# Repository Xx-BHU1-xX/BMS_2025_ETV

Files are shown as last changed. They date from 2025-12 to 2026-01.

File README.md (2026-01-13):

## Project archive for the 2025 ETV BMS
- Refer to the `hardware` section for design choices and PCB files.
- Refer to the `software` section for firmware dev.

## Yet to be implemented:
- Charging control and charger CAN comms
	- Control charging current and voltage according to INR1650 charge specs
	- J1939 CAN implementation for commanding charging current and voltage 
	- Should be relatively straightforard to implement with new task
- Inital SOH estimation
	- Detailed in the task description for `TaskUpdateSOC` 
- DCIR history
	- Store DCIR values in EEPROM for recovery in the next power cycle

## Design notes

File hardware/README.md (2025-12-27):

# Battery Management System (BMS)

---

## Architecture evolution

### Earlier version
- Used **LTC6804-based slave boards (DC1894B)** with a **Linduino (DC2026)** as the isoSPI master.
- The entire system ran on the **ATmega328P** on the DC2026.
- SRAM was very limited (~2 KB), which was barely enough for:
  - 72× cell voltages, SOC, DCIR values
  - filtering / fault flags
- This became the main bottleneck as features were added.

---

### Revised architecture
- High-level processing was offloaded to an **ESP32**.
- The **DC2026** was retained only for reliable LTC6804 isoSPI communication.
- Direct isoSPI from the ESP32 was avoided to keep hardware and isolation simpler (and to avoid porting the LTC sketchbook :)

---

## Communication and isolation
- **ESP32** is referenced to **GLV**.
- **Linduino (DC2026)** is referenced to **TS**.
- Communication between the two is via an **isolated UART**.

---

## Additional features
- CAN communication for vehicle integration.
- Redundant isolated current sensing:
  - Hall-effect sensor (HBO300 fully differential)
  - Shunt-based sensor (VAT4300 wireless)

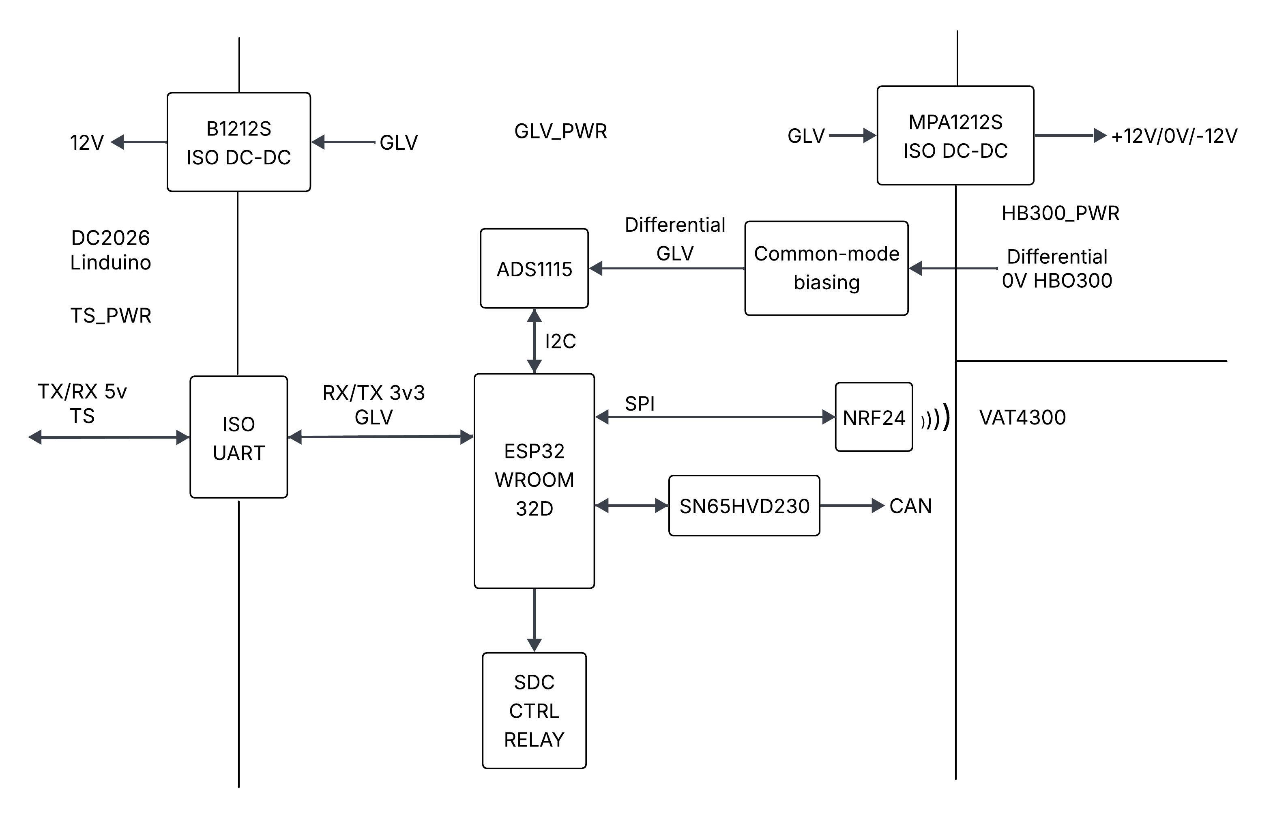
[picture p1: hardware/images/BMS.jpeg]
BMS architecture


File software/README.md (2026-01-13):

## Firmware overview

The BMS firmware runs on the ESP32 using FreeRTOS and is structured as a set of independent tasks, each responsible for one clear function (cell monitoring, SOC/DCIR estimation, current sensing, balancing, fault handling, comms, etc). Most tasks are implemented as simple state machines and communicate with each other using RTOS primitives. The overall focus is on robustness, predictable behavior, and making sure safety-critical logic (especially SDC control) cannot fail.

---

## General firmware practices

### RTOS usage
- Standard FreeRTOS practices are followed:
  - one task per logical function
  - clear ownership of peripherals
  - explicit synchronization between tasks

---

### Data sharing between tasks
- Data between tasks is shared using **queues**.
- In most cases, only the **latest value** matters and older values are irrelevant.
- Hence, almost all queues are created with **length = 1**.
- Writes use `xQueueOverwrite()` to always push the latest value.
- Reads use `xQueuePeek()` so values can be read **non-destructively**.
- This avoids issues like conflicting writes and read/write races.
- Stale data detection is additonaly implemented in fault detection and handling.

---

### Resource management
- Shared peripherals (I2C, SPI, CAN, UART, etc.) are protected using **mutexes**.
- If a task needs a peripheral, it:
  1. takes the mutex  
  2. uses the peripheral  
  3. releases the mutex
- Once a task has taken a mutex, no other task can access that peripheral, even if the original task gets preempted.
- This ensures the reason the task needed the peripheral in the first place doesn’t get corrupted by another task.

---

### Interrupt handling
- ISRs themselves are not part of the RTOS.
- Interrupts are handled using **short ISRs** that simply notify a waiting task.
- The actual processing is always done in task context.

**Important**
- The task must already be waiting for the interrupt **before** the interrupt fires.
- In practice, this means:
  - perform the action
  - wait for the interrupt **in the same state**
- The wait is intentionally not moved into the next state, because any delay between states could cause the interrupt to arrive when the task isn’t waiting, adding unnecessary latency or missing the event altogether.

For task descriptions, refer 
[Full task descriptions (PDF)](docs/BMS_25.pdf)

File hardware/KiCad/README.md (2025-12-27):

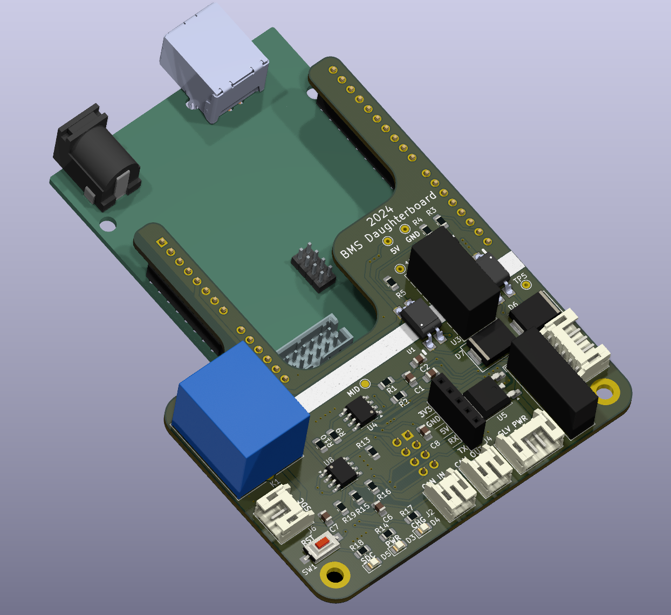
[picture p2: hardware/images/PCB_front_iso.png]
PCB front iso

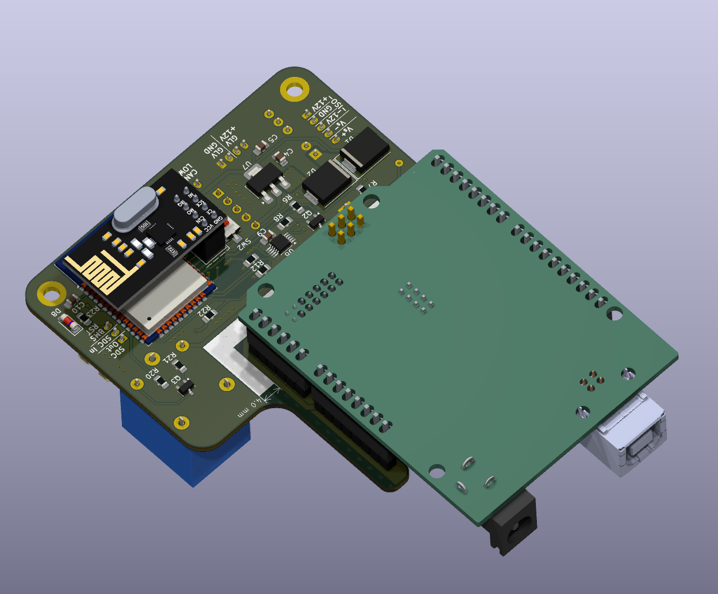
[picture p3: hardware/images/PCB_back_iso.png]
PCB back iso


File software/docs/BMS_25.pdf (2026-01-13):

# Task descriptions

## void TaskLinduinoCVComms(void *pvParameters)

This task handles communication with the Linduino (DC2026) over an isolated UART.

### Communication scheme

### ESP32 → Linduino (request)

- The ESP32 requests 12× cell voltages for a given segment and sends the balancing configuration for that segment.
- The balance configuration is stored as a uint16_t, where each bit represents whether balancing is ON/OFF for a module:
BAL[segment_index] = 0x0XXX (LSB corresponds to module 0).
- Each request packet is 1 byte, encoded as:
- Segment ID (3 bits)
Identifies the requested segment (1–6).
- Balance Index (2 bits)
Selects which 3-bit slice of the 12-bit balance word: ■ 0 → BAL[2:0]
■ 1 → BAL[5:3]
■ 2 → BAL[8:6]
■ 3 → BAL[11:9]
- Balance Config (3 bits)
Balancing ON/OFF for the selected 3 modules.

Notes

- Four request bytes are sent (one per balance index).
- Bytes are sent 1 ms apart.
- Packet is self-identifying; order does not matter.

### Linduino → ESP32 (response)

- The Linduino receives the 4 bytes and reconstructs the full 12-bit balance configuration for the requested segment.
- It responds with 26 bytes in the following format:
- Byte 0 : Segment ID (Same as request, extended to 8 bits (0x01 - 0x06))
- Byte 1–24 : 12 × uint16_t Cell Voltages (big-endian)
- Byte 25 : CRC (8-bit)

Details

- Cell voltages start from module 0.
- Each cell voltage is uint16_t (actual CellV * 10000)
- CRC is calculated over the 12 × 16-bit cell voltage data only.
- CRC polynomial: 100000111

### ESP32 receive handling

- The ESP32 reads the 26-byte response.
- It first checks that the segment index matches the requested segment.
- If not, the serial stream is flushed and the packet is ignored.
- The CRC is verified.
- If valid, the received cell voltages are pushed to the cell-voltage queue.
- The ESP32 then requests data for the next segment, and the cycle repeats.

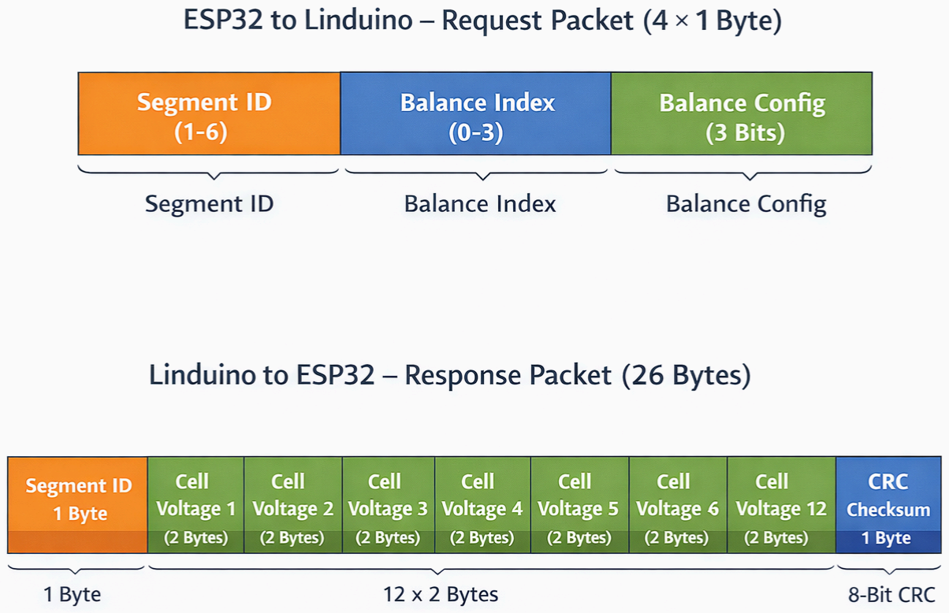
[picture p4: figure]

## void TaskUpdateSOC(void *pvParameters)

This task updates SOC using two methods and then fuses them.

### Method 1: SOC1 (voltage-based)

- The task estimates OCV using:
- OCV = CellV + (TS_current + I_balance_if_ON) * DCIR
- It then estimates SOC from OCV using your piecewise 3rd-order fit:
- SOC1 = OCV2SOC(OCV)

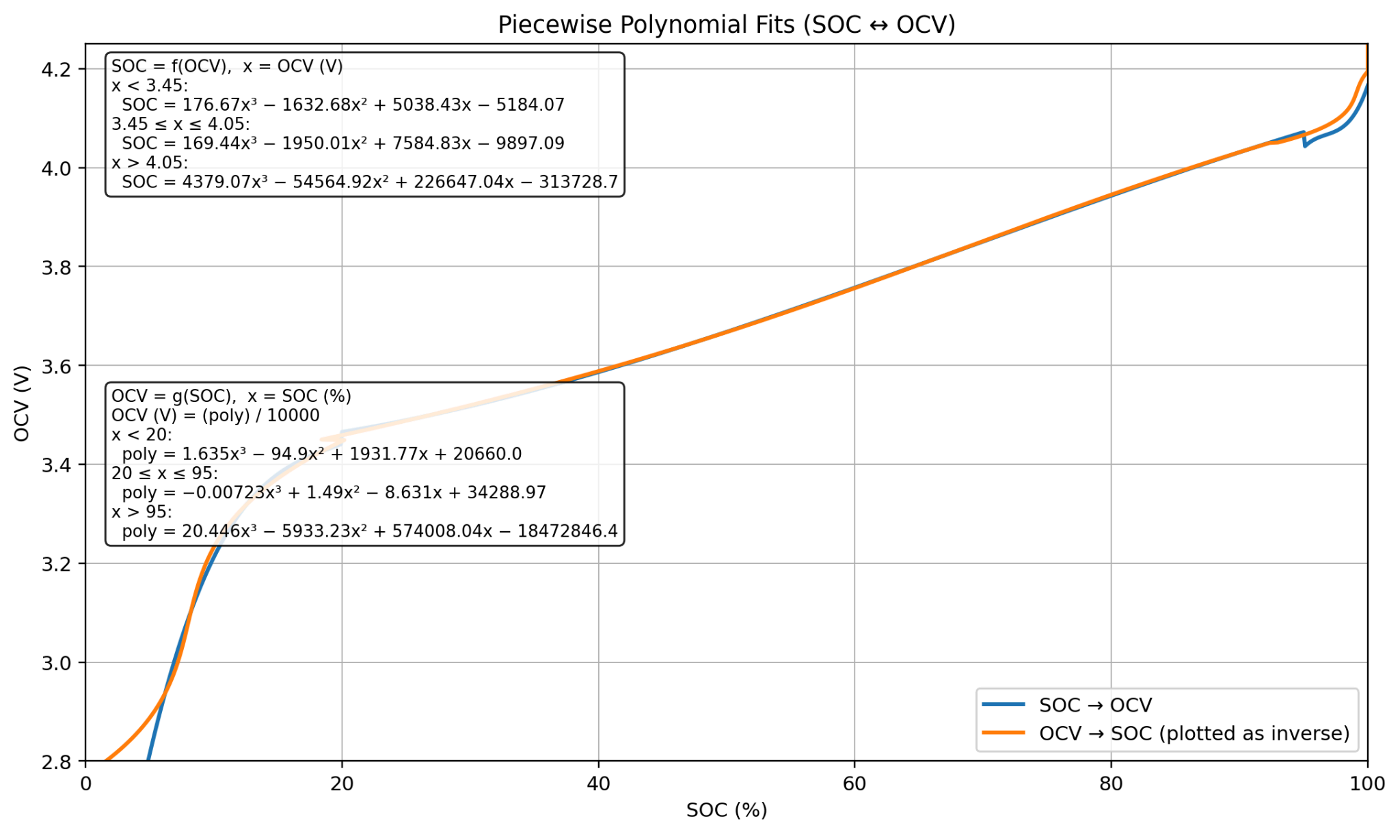
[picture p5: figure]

### Method 2: SOC2 (coulomb counting)

- SOC2 is updated using coulomb counting:
- SOC2 = SOC2_prev - (TS_current * Δt) / MOD_Capacity
- Here MOD_Capacity = 25Ah, and Δt = (current_update_time - last_update_time).

### Fusion: complementary filter

- SOC1 is trusted only at low current, so the blend factor is:
- alpha = max(0, (1 - abs(TS_current)/I_threshold))
- Final SOC is:
- SOC_final = alpha*SOC1 + (1-alpha)*SOC2

Notes

- SOC2 needs initialization, so on the first update:
- SOC1 = SOC2 = OCV2SOC(OCV)
- If the actual module capacity is less than MOD_Capacity (25Ah), SOC2 will change slower than SOC1 during discharge.
- The ratio ΔSOC2 / ΔSOC1 can be used as a rough SOH estimate (since SOC2 assumes ideal capacity).
- There are small discontinuities at the boundaries of the piecewise polynomial fit.
- Even with these discontinuities, the fits were chosen such that within each region, repeated inter-conversion OCV → SOC → OCV → … will still converge, even in the presence of floating-point rounding error.
- This task starts only after the first round of cellVs for all 6 segments have been received (TaskLinduinoCVComms gives a notification)

## void TaskUpdateDCIR(void *pvParameters)

This task updates DCIR dynamically during operation.

### DCIR update equation

DCIR is estimated as:

- DCIR_new = (SOC2OCV(SOC_final) - CellV) / (TS_current + I_balance_if_ON)

Limits + jump filtering

The new DCIR is accepted only if:

- DCIR_MIN_LIMIT < DCIR_new < DCIR_MAX_LIMIT
- AND abs(DCIR_new - DCIR_old) < DCIR_JUMP_LIMIT
- Example limits:
- DCIR_MIN_LIMIT = 2500 µΩ
- DCIR_MAX_LIMIT = 5000 µΩ
- DCIR_JUMP_LIMIT = 1000 µΩ

### Smoothing

If the limits pass, DCIR is updated using exponential smoothing:

- DCIR = beta*DCIR_new + (1-beta)*DCIR_old

Note

- The clipping + jump limit + smoothing is mainly to reduce noise and to average out effects like cell polarization (so DCIR doesn’t go nuts due to transients).
- This task only starts after the first round of SOCs have been estimated for all modules (TaskUpdateSOC) gives a notification

## void TaskADS1115(void *pvParameters)

- Interfacing with all peripherals like ADS1115 (I2C), NRF24 (SPI), CAN, etc are handled using state machines.
- Of course the Adafruit library exists for interfacing with the ADS1115, but it suffers from a flaw. It uses polling (the OS bit of the config register is polled continuously to check if the conversion is complete). However this isn’t ideal for RTOS as other tasks could be run during the ADC conversion time. Hence an interrupt triggered, thread safe driver was built from scratch.
- Shared bus/resources are protected using mutexes (see Resource management section in the intro).
- ADS1115 conversions run in single-shot mode.
- The ESP32 starts conversions, and the I2C read is triggered by the active-low RDY interrupt on GPIO14.
- ADS1115 I2C address is 0b1001000 (0x48) since ADDR is tied to GND.

### State 0 — Write config (setup)

- Write 0x0380 to Config register (pointer = 0x01).
- Bitfields:
- OS (bit 15) = 0 (not starting conversion yet)
- MUX (14:12) = 000 (AIN0 − AIN1)
- PGA (11:9) = 001 (±4.096 V, since HBO300 outputs ±4 V)
- MODE (8) = 1 (single-shot)
- DR (7:5) = 100 (128 SPS default, not critical in single-shot)
- COMP_MODE (4) = 0 (don’t care for RDY)
- COMP_POL (3) = 0 (active-low RDY)
- COMP_LAT (2) = 0 (don’t care for RDY)
- COMP_QUE (1:0) = 00 (anything except 11 works)
- If the I2C write succeeds (all bytes ACK’d), go to State 1.

### State 1 — Write Lo_thresh (enable RDY)

- Write 0x0000 to Lo_thresh (pointer = 0x02).
- RDY mode needs MSB of Lo_thresh = 0.
- If the I2C write succeeds, go to State 2.

### State 2 — Write Hi_thresh (enable RDY)

- Write 0x8000 to Hi_thresh (pointer = 0x03).
- RDY mode needs MSB of Hi_thresh = 1.
- If the I2C write succeeds, go to State 3.

### State 3 — Start conversion + wait for RDY + read

- Write 0x8380 to Config (same as State 0, but OS = 1 to start conversion).
- Wait for the interrupt notification from the RDY pin.
- The same state that triggers conversion also waits for the notification.
- This is intentional because the state machine has a 2 ms delay between states, and splitting the wait into another state could add up to ~2 ms of extra latency if the RDY interrupt arrives when the task isn’t scheduled.
- Once the notification is received from the ISR, write 0x00 to the pointer register to select Conversion register (pointer = 0x00).
- Request a 2-byte I2C read and read the conversion register.
- If 2 bytes are received successfully, go to State 4.

### State 4 — Process + queue

- Read the 2 bytes from the I2C buffer into memory.
- Use the first 10 readings to estimate an average zero-current bias.
- Push the raw conversion value into the ADS1115Current queue.
- Every ADS1115_CONFIG_REWRITE_CYCLES (100 conversions), rewrite config from State 0–2.
- Otherwise, go back to State 3 and start the next conversion.

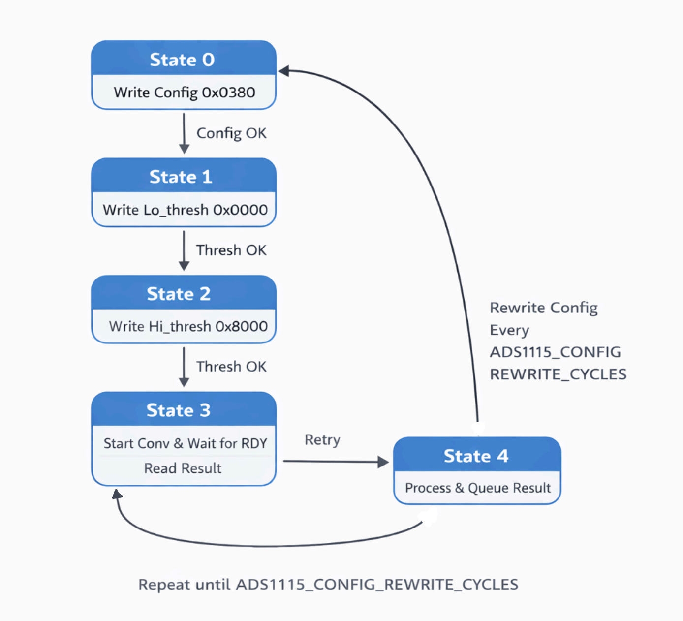
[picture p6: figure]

## void TaskVAT4300(void *pvParameters)

- The VAT4300 shunt uses an nRF24 link with a proprietary protocol.
- The protocol + config was reverse engineered by Robert Flately (https://www.youtube.com/redirect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) (Youtube video) (https://www.youtube.com/watch?v=S0-O9cTS9Uw)
- This task is basically a clean, state-machine based, thread-safe version of that approach.
- Implementation uses the RF24 Arduino library.

### Comms scheme (state machine)

### State 0 — Radio setup (address + frequency)

- The VAT4300 needs two critical settings:
- VAT4300_address
- VAT4300_frequency
- These are normally set by the original base station, but since that was lost, they were recovered by probing the VAT4300 nRF24 SPI lines on a scope + serial decode.
- The TX/RX pipes are opened (pipe 0) using the correct address and frequency.
- Auto-ACK is enabled for pipe 0.

### State 1 — Transmit frame + wait for a valid RX (IRQ handling)

- Default TX payload format is:
- 0xAA 0x04 0x01 <VAT4300_address> <28 bytes of 0x00>
- For the first initialization frame:
- TX_payload[2] = 0xFF
- TX_payload[4] = VAT4300_address + 0xAD
- For all normal frames after init:
- TX_payload[2] = 0x01
- TX_payload[4] = VAT4300_address + 0xAF
- The frame is transmitted, and then the radio switches to listening mode.

Important: NRF24 IRQ behavior

- IRQ (active-low) asserts for multiple reasons:
- TX success (ACK received) (radio.write() returns true)
- TX fail (MAX_RT) (radio.write() eventually returns false)
- RX data received (RX_DR)
- In this task, IRQ is used only as a signal for successful RX reception from the VAT4300.
- Since TX events also trigger IRQ, the task clears any stale notification right after TX using:
- xTaskNotifyStateClear(VAT4300_Task_Handle)

- After clearing, the task switches to RX mode and waits (max 1s) for a valid RX notification.
- If no RX notification arrives:
- Retransmit up to VAT4300_RESET_CONFIG_RETRIES
- If still nothing, reset the radio config by going back to State 0

### State 2 — Read RX payload

- Read the full 32-byte RX frame.
- The first RX after TX init is ignored (has VAT4300 config data)

### State 3 — Parse + push to queues

- Parse the RX frame and push decoded values to queues.
- Values received:
- TS_voltage
- VAT4300_current
- TS_power
- VAT4300 “on-time” (runtime / uptime)

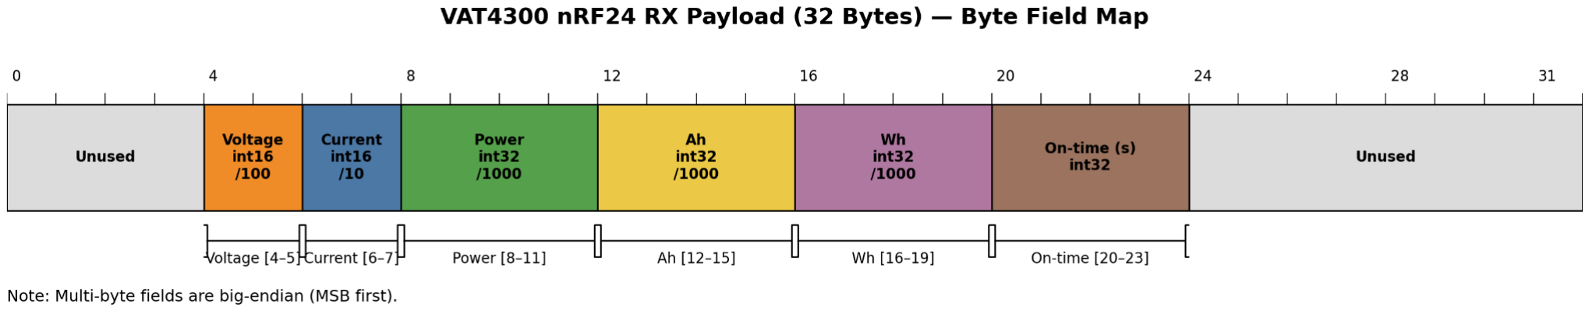
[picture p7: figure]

## void TaskBalancing(void *pvParameters)

- For each segment, the task finds the module with the minimum SOC.
- If any module has:
- SOC > (min_soc_of_segment + BALANCE_THRESHOLD)
then that module’s balancing bit is set to 1 for that segment.
- The task overwrites the BAL queue (used by TaskLinduinoCVComms) with the latest balance config.

## void TaskUpdateTSCurrent(void *pvParameters)

- The VAT4300 shunt current is trusted more than the fast-sampled Hall sensor (HBO300).
- If a new VAT4300 current value was recently updated by TaskVAT4300, TS_current is set to that value.
- Otherwise, the HBO300 value is used.

### ADS1115 → HBO300 current conversion

- Raw ADS1115 readings are converted to current using:
- HBO300_ADS1115_CURRENT_MULTIPLY_FACTOR
- The theoretical factor is:
- ADS1115_resolution = 125 µV/LSB (±4.096V range)
- HBO300 scale = 300A / 4V
- So:
■ 125e-6 * (300/4) = 0.009375 A/LSB
- With real-world calibration this factor is set to:
- 0.01 A/LSB

## void TaskSDCFault(void *pvParameters)

- This is one of the most important tasks.
- It is the only user-defined task added to the ESP WDT (apart from the default WiFi background task).

Why this task exists (main failure mode)

- Tasks share data through queues using:
- Queue overwrite for writes
- Queue peek for non-destructive reads
- If a peripheral fails, the queue stops updating, but still holds the last valid value, which can silently hide failures.
- This is especially critical for the isolated UART link between ESP32 and Linduino (TaskLinduinoCVComms).

### Fault checks (and which counter increments)

1) Linduino comms “stuck data” detection →

fault_counter[2]

- For each segment, the received cell codes are XOR’d together to form a per-segment “XOR signature”.
- The XOR signatures are compared against the previous cycle.
- If the XOR signature does not change while TS_current != 0, it indicates the cell data is no longer updating → UART link is likely down.
- In that case:
- fault_counter[2]++
2) SOC out-of-bounds (cell V protection and SOC estimation check) →

fault_counter[0]

- If any cell/module SOC goes outside:
- SOC_MIN_FAULT and SOC_MAX_FAULT
- Then:
- fault_counter[0]++
3) Current sensor disagreement →

fault_counter[1]

- If:
- abs(I_VAT4300 - I_HBO300) > CURRENT_DEV_FAULT
- Then:
- fault_counter[1]++

### WDT behavior + fault latching

- As long as all fault counters are < 10, this task continues to reset the WDT.
- If any fault counter reaches >= 10:
- All primary tasks are suspended
- The SDC relay is opened
- The task enters an infinite loop (so the WDT is no longer reset)
- Once the WDT expires, the ESP32 triggers a software reset.
- In setup(), the reset reason is checked:
- If the reset was due to WDT timeout, setup() enters an infinite loop and the BMS stays disabled until a manual hardware reset.

This ensures fault latching: the SDC only closes again after faults are fixed and the BMS is manually reset.

## void TaskTelnetStreamPrintDebug(void *pvParameters)

- This task provides a live Telnet debug stream for quick runtime inspection.
- The ESP32 connects to the local WiFi network and serves a Telnet stream (use PuTTY to connect).
- A simple menu is printed, and the user can type commands to continuously print values.

### Menu

Instructions to print debug info

- Enter 1x to print SOC of x (0...) segment
- Enter 2x to print DCIR of x (0...) segment
- Enter 3x to print CellV of x (0...) segment
- Enter 4 to print VAT4300 current value
- Enter 5 to print ADS1115 raw values
- Enter 6 to print TS current value
- Enter 7 for current bias
- Enter 8 for VAT4300 on time
- Enter 0 for instructions

### Example

- Entering for ex, “13”, continuously prints SOCs of all modules in segment 3 (0-5).
- 0 can be entered anytime to return to the main menu.

## void TaskOTAHandleAlive(void *pvParameters)

- This task was originally used to connect to WiFi.
- If connection fails, it retries every OTA_RETRY_DELAY_MS.
- It keeps the OTA handle alive.
- Once WiFi is connected, it sends a start notification to TaskTelnetStreamPrintDebug.

## void TaskCANComms(void *pvParameters)

- This task uses the ESP32 TWAI CAN library to transmit CAN messages.
- All data is little-endian.

### CAN messages

1. ID = 0x5AA
- 8 bytes total
- float TS_current (4 bytes) + float TS_voltage (4 bytes)
2. ID = 0x5AB
- 4 bytes total
- float TS_power
3. ID = 0x5AC
- 8 bytes total
- float HBO300_current (4 bytes) + float VAT4300_current (4 bytes)
4. ID = 0x5AD
- 7 bytes total
- uint16_t DCIR_total_mOhm (2 bytes, sum of all modules)
- float TS_voltage_total (4 bytes, pack voltage)
- uint8_t SOC_avg (1 byte, avg of all modules)

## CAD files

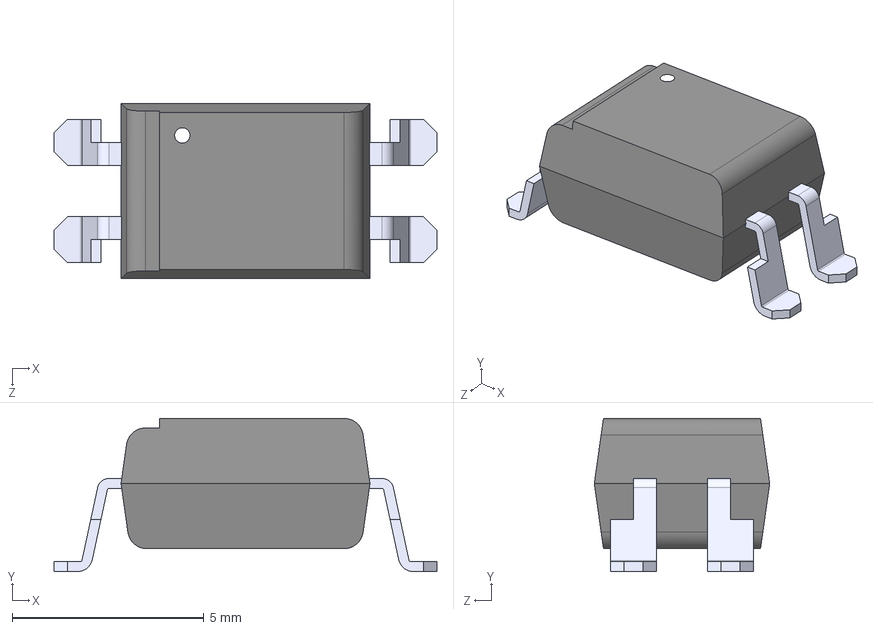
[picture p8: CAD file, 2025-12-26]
hardware/KiCad/Footprints/PC817.step
10.0 x 4.00 x 4.58 mm

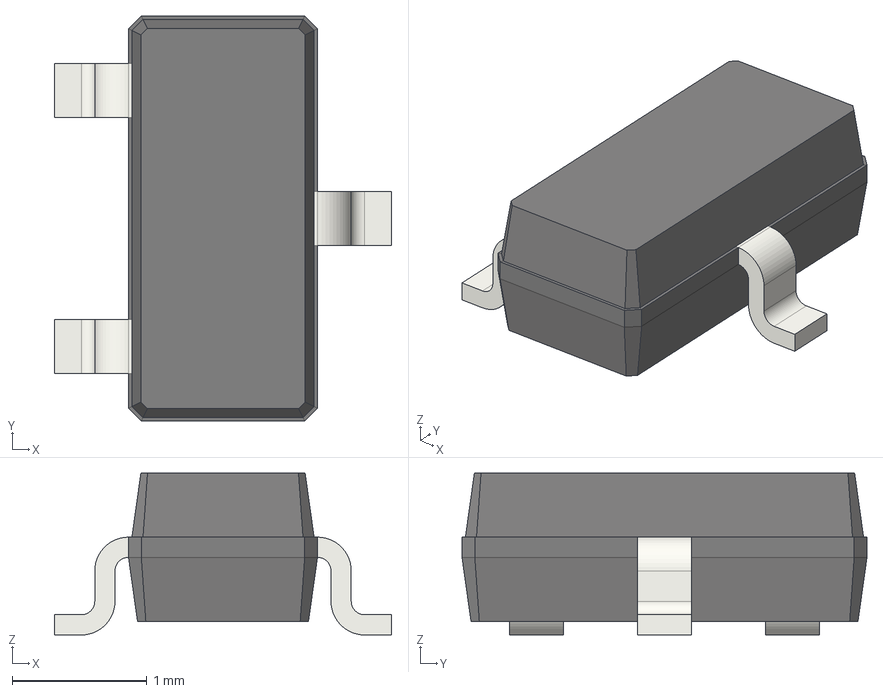
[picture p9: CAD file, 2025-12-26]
hardware/KiCad/Footprints/SOT-23.step
2.50 x 3.00 x 1.20 mm

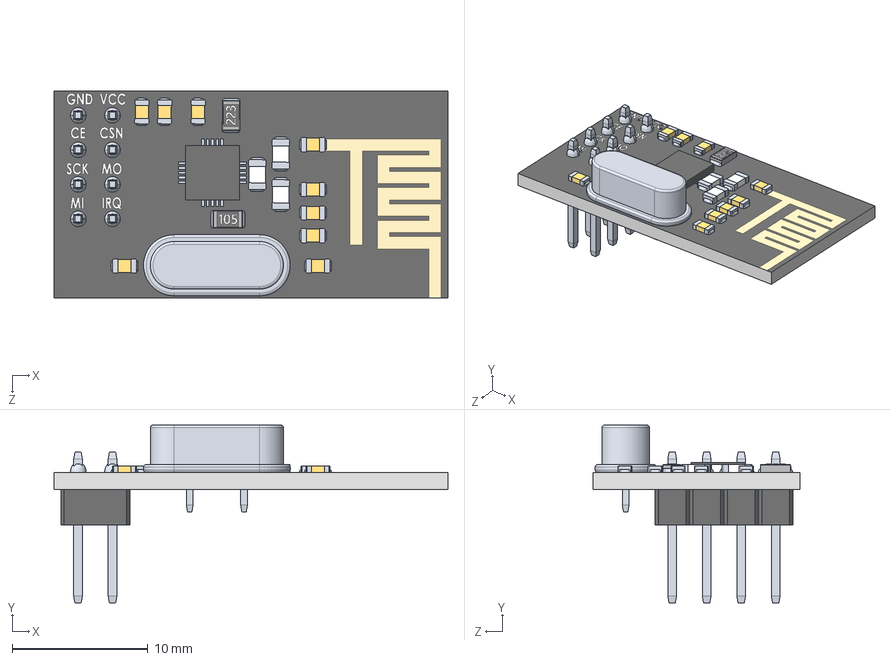
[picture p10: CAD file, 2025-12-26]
hardware/KiCad/Footprints/nRF24L01 Breakout Board.step
29.0 x 13.1 x 15.2 mm
nrfboard
CrystalOscillator
doubleMaleHeader x 4
solder x 8
1.7mmSmdCeramicCapacitor x 9
smdResistor223
smdResistor105
smdceramiccapacitorwhite x 3
4x4SMDchip

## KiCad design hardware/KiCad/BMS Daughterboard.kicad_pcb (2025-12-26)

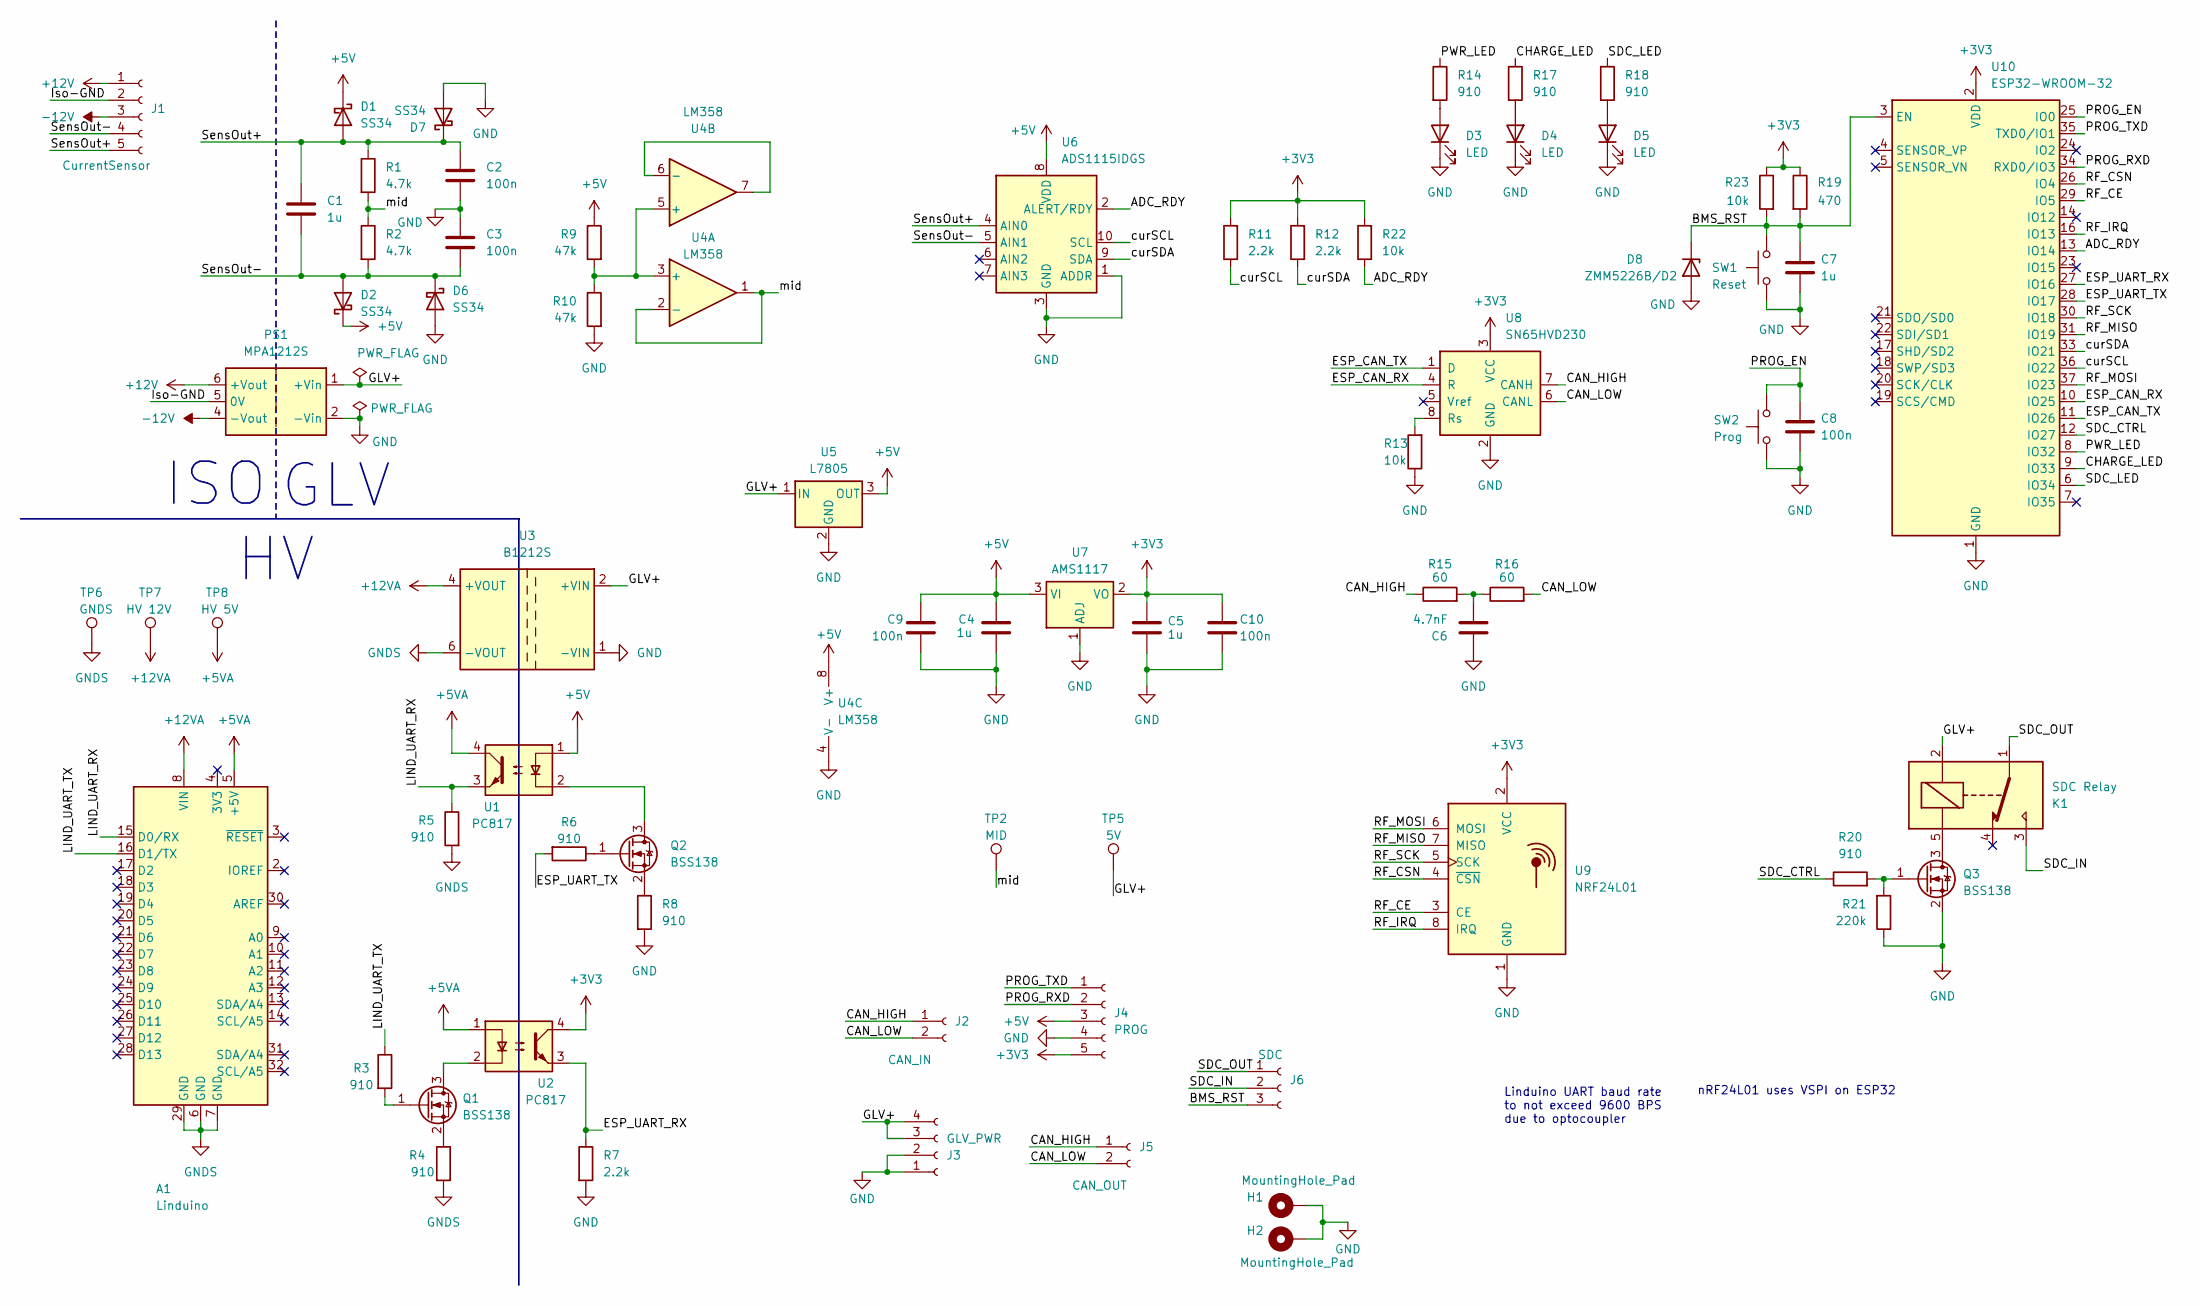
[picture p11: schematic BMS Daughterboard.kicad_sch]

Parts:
A1: Linduino
C1, C4, C5, C7: 1u; C_0805_2012Metric_Pad1.18x1.45mm_HandSolder
C2, C3, C8, C9, C10: 100n; C_0805_2012Metric_Pad1.18x1.45mm_HandSolder
C6: 4.7nF; C_0805_2012Metric_Pad1.18x1.45mm_HandSolder
D1, D2, D6, D7: SS34; D_SMC
D3, D4, D5: LED; LED_0805_2012Metric_Pad1.15x1.40mm_HandSolder
D8: ZMM5226B/D2; D_MiniMELF
H1, H2: MountingHole_Pad; MountingHole_3.2mm_M3_DIN965_Pad
J1: CurrentSensor; JST_PH_S5B-PH-K_1x05_P2.00mm_Horizontal
J2: CAN_IN; JST_PH_S2B-PH-K_1x02_P2.00mm_Horizontal
J3: GLV_PWR; JST_PH_S4B-PH-K_1x04_P2.00mm_Horizontal
J4: PROG; PinSocket_1x05_P2.54mm_Vertical
J5: CAN_OUT; JST_PH_S2B-PH-K_1x02_P2.00mm_Horizontal
J6: SDC; JST_PH_S3B-PH-K_1x03_P2.00mm_Horizontal
K1: SDC Relay; Relay_SPDT_SANYOU_SRD_Series_Form_C
PS1: MPA1212S; Converter_DCDC_XP_POWER-IAxxxxS_THT
Q1, Q2, Q3: BSS138
R1, R2: 4.7k; R_0805_2012Metric_Pad1.20x1.40mm_HandSolder
R3, R4, R5, R6, R8, R14, R17, R18, R20: 910; R_0805_2012Metric_Pad1.20x1.40mm_HandSolder
R7, R11, R12: 2.2k; R_0805_2012Metric_Pad1.20x1.40mm_HandSolder
R9, R10: 47k; R_0805_2012Metric_Pad1.20x1.40mm_HandSolder
R13, R22, R23: 10k; R_0805_2012Metric_Pad1.20x1.40mm_HandSolder
R15, R16: 60; R_0805_2012Metric_Pad1.20x1.40mm_HandSolder
R19: 470; R_0805_2012Metric_Pad1.20x1.40mm_HandSolder
R21: 220k; R_0805_2012Metric_Pad1.20x1.40mm_HandSolder
SW1: Reset; Push Button
SW2: Prog; Push Button
TP2: MID; TestPoint_Pad_D1.5mm
TP5: 5V; TestPoint_THTPad_D1.5mm_Drill0.7mm
TP6: GNDS; TestPoint_THTPad_D1.5mm_Drill0.7mm
TP7: HV 12V; TestPoint_THTPad_D1.5mm_Drill0.7mm
TP8: HV 5V; TestPoint_THTPad_D1.5mm_Drill0.7mm
U1, U2: PC817
U3: B1212S; DCDC B1212S
U4: LM358; SOIC-8_3.9x4.9mm_P1.27mm
U5: L7805; TO-252-2
U6: ADS1115IDGS; VSSOP-10_3x3mm_P0.5mm
U7: AMS1117; SOT-223-3_TabPin2
U8: SN65HVD230; SOIC-8_3.9x4.9mm_P1.27mm
U9: NRF24L01; nRF24L01_Breakout
U10: ESP32-WROOM-32

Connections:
+3V3: C5.1, C10.1, J4.5, R11.2, R12.2, R19.1, R22.2, R23.1, U2.4, U7.2 (VO), U8.3 (VCC), U9.2 (VCC), U10.2 (VDD)
+5V: C4.1, C9.1, D1.1 (K), D2.1 (K), J4.3, R9.1, U1.1, U4.8 (V+), U5.3 (OUT), U6.8 (VDD), U7.3 (VI)
+5VA: A1.5 (+5V), TP8.1, U1.4, U2.1
+12V: J1.1, PS1.6 (+Vout)
+12VA: A1.8 (VIN), TP7.1, U3.4 (+VOUT)
-12V: J1.3, PS1.4 (-Vout)
/ADC_RDY: R22.1, U6.2 (ALERT/RDY), U10.13 (IO14)
/BMS_RST: C7.1, D8.1 (K), J6.3, R19.2, R23.2, SW1.2, U10.3 (EN)
/CAN_HIGH: J2.1, J5.1, R15.1, U8.7 (CANH)
/CAN_LOW: J2.2, J5.2, R16.2, U8.6 (CANL)
/CHARGE_LED: R17.1, U10.9 (IO33)
/ESP_CAN_RX: U8.4 (R), U10.10 (IO25)
/ESP_CAN_TX: U8.1 (D), U10.11 (IO26)
/ESP_UART_RX: R7.1, U2.3, U10.27 (IO16)
/ESP_UART_TX: R6.2, U10.28 (IO17)
/GLV+: J3.3, J3.4, K1.2, PS1.1 (+Vin), TP5.1, U3.2 (+VIN), U5.1 (IN)
/Iso-GND: J1.2, PS1.5 (0V)
/LIND_UART_RX: A1.15 (D0/RX), R5.1, U1.3
/LIND_UART_TX: A1.16 (D1/TX), R3.1
/PROG_EN: C8.1, SW2.2, U10.25 (IO0)
/PROG_RXD: J4.2, U10.34 (RXD0/IO3)
/PROG_TXD: J4.1, U10.35 (TXD0/IO1)
/PWR_LED: R14.1, U10.8 (IO32)
/RF_CE: U9.3 (CE), U10.29 (IO5)
/RF_CSN: U9.4 (~CSN), U10.26 (IO4)
/RF_IRQ: U9.8 (IRQ), U10.16 (IO13)
/RF_MISO: U9.7 (MISO), U10.31 (IO19)
/RF_MOSI: U9.6 (MOSI), U10.37 (IO23)
/RF_SCK: U9.5 (SCK), U10.30 (IO18)
/SDC_CTRL: R20.1, U10.12 (IO27)
/SDC_IN: J6.2, K1.3
/SDC_LED: R18.1, U10.6 (IO34)
/SDC_OUT: J6.1, K1.1
/SensOut+: C1.1, C2.1, D1.2 (A), D7.1 (K), J1.5, R1.1, U6.4 (AIN0)
/SensOut-: C1.2, C3.2, D2.2 (A), D6.1 (K), J1.4, R2.2, U6.5 (AIN1)
/curSCL: R11.1, U6.10 (SCL), U10.36 (IO22)
/curSDA: R12.1, U6.9 (SDA), U10.33 (IO21)
/mid: R1.2, R2.1, TP2.1, U4.1, U4.2 (-)
GND: C2.2, C3.1, C4.2, C5.2, C6.1, C7.2, C8.2, C9.2, C10.2, D3.1 (K), D4.1 (K), D5.1 (K), D6.2 (A), D7.2 (A), D8.2 (A), H1.1, H2.1, J3.1, J3.2, J4.4, PS1.2 (-Vin), Q3.2 (S), R7.2, R8.2, R10.2, R13.1, R21.1, SW1.1, SW2.1, U3.1 (-VIN), U4.4 (V-), U5.2 (GND), U6.1 (ADDR), U6.3 (GND), U7.1 (ADJ), U8.2 (GND), U9.1 (GND), U10.1 (GND), U10.15 (GND), U10.38 (GND), U10.39 (GND)
GNDS: A1.6 (GND), A1.7 (GND), A1.29 (GND), R4.2, R5.2, TP6.1, U3.6 (-VOUT)
unnamed: C6.2, R15.2, R16.1
unnamed: D3.2 (A), R14.2
unnamed: D4.2 (A), R17.2
unnamed: D5.2 (A), R18.2
unnamed: Q1.3 (D), U2.2
unnamed: Q1.1 (G), R3.2
unnamed: Q1.2 (S), R4.1
unnamed: Q2.3 (D), U1.2
unnamed: Q2.1 (G), R6.1
unnamed: Q2.2 (S), R8.1
unnamed: K1.5, Q3.3 (D)
unnamed: Q3.1 (G), R20.2, R21.2
unnamed: R9.2, R10.1, U4.3 (+), U4.5 (+)
unnamed: U4.6 (-), U4.7
unnamed: R13.2, U8.8 (Rs)

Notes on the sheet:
GLV
nRF24L01 uses VSPI on ESP32
Linduino UART baud rate to not exceed 9600 BPS due to optocoupler
ISO

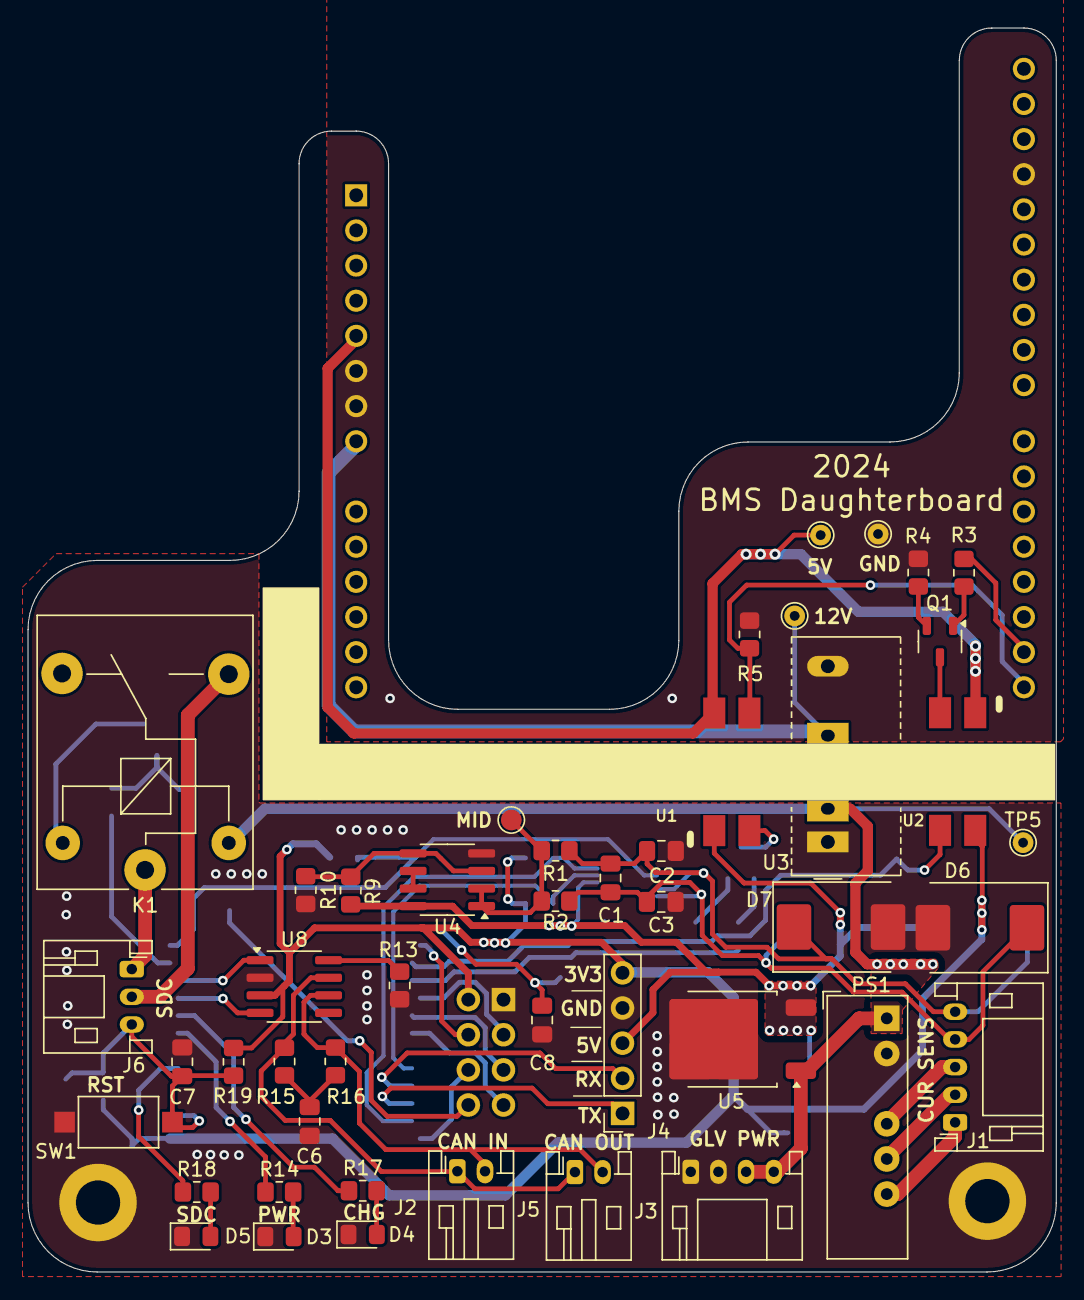
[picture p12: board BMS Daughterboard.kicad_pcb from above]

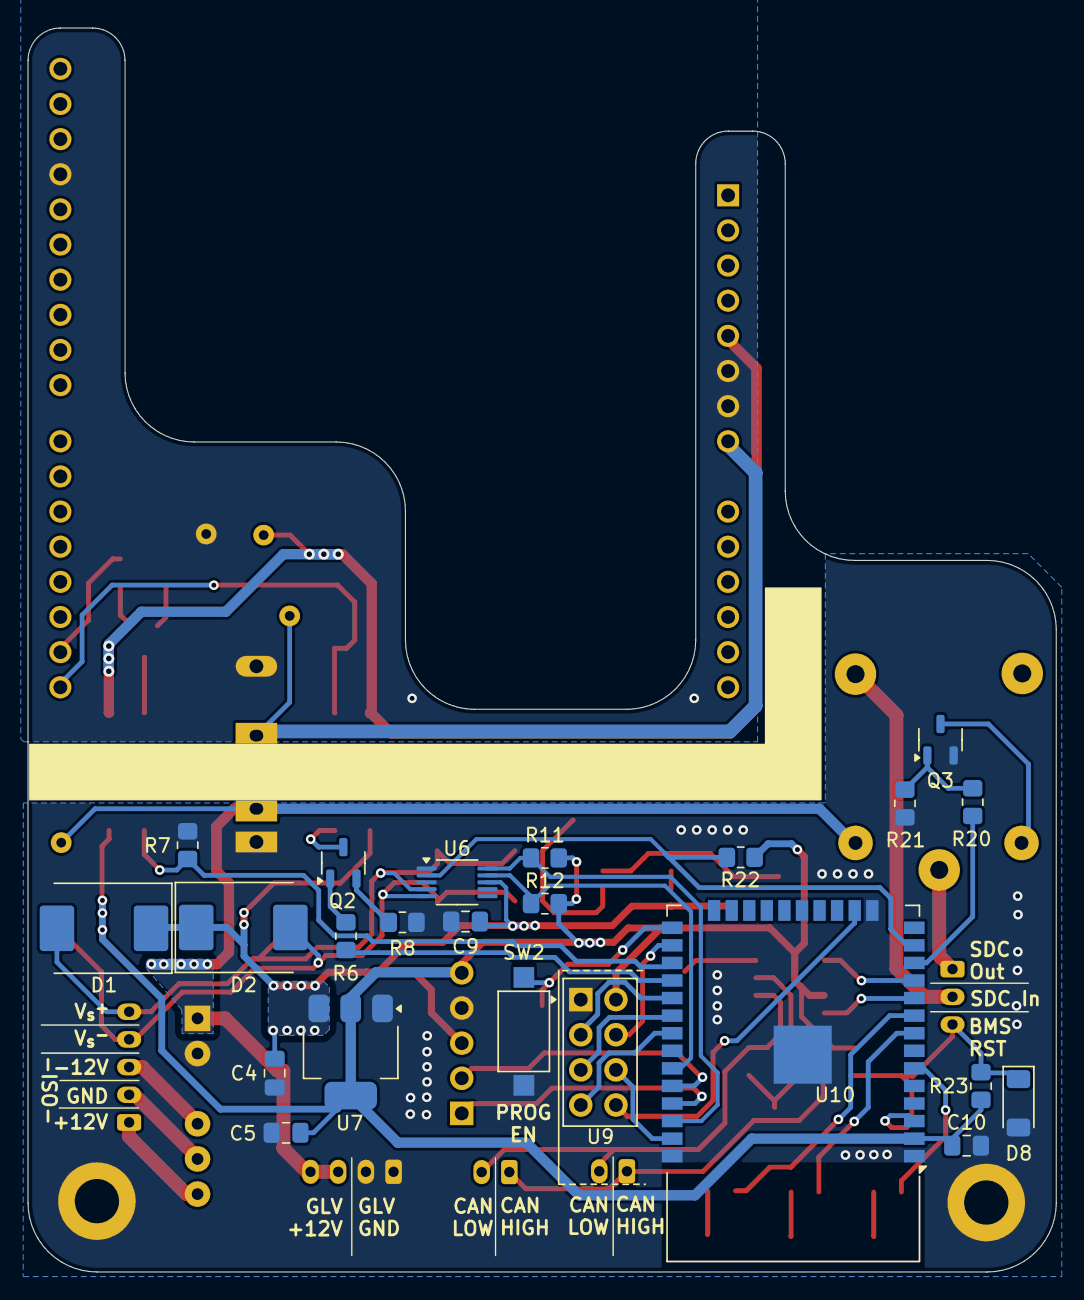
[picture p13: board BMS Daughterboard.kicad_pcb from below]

Board: 2 copper layers, 74.3 x 89.9 mm, 72 parts (23 on the bottom side), 55 nets.

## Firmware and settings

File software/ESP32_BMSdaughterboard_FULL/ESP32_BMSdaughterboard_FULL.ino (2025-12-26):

#define NUM_SEG 6
#define NUM_MOD_SEG 12
#define I_SOC_TRESHOLD 5
#define I_DCIR_TRESHOLD 5
#define MOD_CAPACITY 25
#define DCIR_MIN_LIMIT 2500
#define DCIR_MAX_LIMIT 5000
#define DCIR_JUMP_LIMIT 1000
#define BETA 0.1
#define SOC_MIN_LIMIT 0
#define SOC_MAX_LIMIT 100
#define SOC_MAX_FAULT 100
#define SOC_MIN_FAULT 0
#define ADS1115_CONFIG_REWRITE_CYCLES 100
#define RF24_CE_PIN 5
#define RF24_CSN_PIN 4
#define RF24_IRQ_PIN 13
#define BALANCE_TRESHOLD 7
#define BALANCE_RES_VALUE 33
#define HBO300_ADS1115_CURRENT_MULTIPLY_FACTOR 0.01
#define ADS1115_RDY_PIN 14
#define SDC_CTRL_PIN 27
#define PWR_LED_PIN 32
#define CURRENT_DEV_FAULT 5
#define CELLV_CHANGE_CURRENT 5
#define VAT4300_RESET_CONFIG_RETRIES 20
#define CAN_TX 26
#define CAN_RX 25
#define OTA_RETRY_DELAY_MS 3000

#include <Wire.h>
TwoWire I2CADS1115 = TwoWire(0);

#include <SPI.h>
#include "RF24.h"
#include "esp_task_wdt.h"
#include "esp_system.h"
#include "OTA.h"
#include <ESP32-TWAI-CAN.hpp>

float VAT4300_bias = 0;
float ADS1115_bias = 0;

void TaskLinduinoCVComms(void *pvParameters);
void TaskUpdateSOC(void *pvParameters);
void TaskUpdateDCIR(void *pvParameters);
void TaskADS1115(void *pvParameters);
void TaskVAT4300(void *pvParameters);
void TaskBalancing(void *pvParameters);
void TaskUpdateTSCurrent(void *pvParameters);
void TaskSDCFault(void *pvParameters);
void TaskTelnetStreamPrintDebug(void *pvParameters);
void TaskOTAHandleAlive(void *pvParameters);
void TaskCANComms(void *pvParameters);

TaskHandle_t Linduino_CV_Comms_Task_Handle;
TaskHandle_t Update_SOC_Task_Handle;
TaskHandle_t Update_DCIR_Task_Handle;
TaskHandle_t ADS1115_Task_Handle;
TaskHandle_t VAT4300_Task_Handle;
TaskHandle_t Balancing_Task_Handle;
TaskHandle_t Update_TS_Current_Task_Handle;
TaskHandle_t SDC_Fault_Task_Handle;
TaskHandle_t TelnetStream_Print_Debug_Task_Handle;
TaskHandle_t OTA_Handle_Alive_Task_Handle;
TaskHandle_t CAN_Comms_Task_Handle;

SemaphoreHandle_t linduino_serial_mutex = NULL;
SemaphoreHandle_t i2c_mutex = NULL;
SemaphoreHandle_t rf24_mutex = NULL;
SemaphoreHandle_t telnet_mutex = NULL;
SemaphoreHandle_t twai_mutex = NULL;

QueueHandle_t cellV[NUM_SEG][NUM_MOD_SEG];  //in 100uV steps
QueueHandle_t SOC1[NUM_SEG][NUM_MOD_SEG];   //in uint percent like 95
QueueHandle_t SOC2[NUM_SEG][NUM_MOD_SEG];   //in uint percent like 95
QueueHandle_t DCIR[NUM_SEG][NUM_MOD_SEG];   //in micro ohms
QueueHandle_t SOC[NUM_SEG][NUM_MOD_SEG];    //in uint percent like 95
QueueHandle_t BAL[NUM_SEG];
QueueHandle_t TSCurrent;
QueueHandle_t SOCCoulombCountingTime;
QueueHandle_t ADS1115Current;
QueueHandle_t VAT4300Current;
QueueHandle_t TSVoltage;
QueueHandle_t TSPower;
QueueHandle_t VAT4300OnTimeSeconds;

float soc_to_ocv_above_95[4] = { -18472846.4, 574008.04, -5933.23, 20.446 };
float soc_to_ocv_below_20[4] = { 20660.0, 1931.77, -94.9, 1.635 };
float soc_to_ocv_middle[4] = { 34288.97, -8.631, 1.49, -0.00723 };
float ocv_to_soc_above_4_05[4] = { -313728.7, 226647.04, -54564.92, 4379.07 };
float ocv_to_soc_below_3_45[4] = { -5184.07, 5038.43, -1632.68, 176.67 };
float ocv_to_soc_middle[4] = { -9897.09, 7584.83, -1950.01, 169.44 };


void IRAM_ATTR ads1115ISR() {
  BaseType_t xHigherPriorityTaskWoken = pdFALSE;
  vTaskNotifyGiveFromISR(ADS1115_Task_Handle, &xHigherPriorityTaskWoken);
  portYIELD_FROM_ISR(xHigherPriorityTaskWoken);
}

void IRAM_ATTR rf24ISR() {
  BaseType_t xHigherPriorityTaskWoken = pdFALSE;
  vTaskNotifyGiveFromISR(VAT4300_Task_Handle, &xHigherPriorityTaskWoken);
  portYIELD_FROM_ISR(xHigherPriorityTaskWoken);
}

void setup() {
  pinMode(SDC_CTRL_PIN, OUTPUT);
  pinMode(PWR_LED_PIN, OUTPUT);
  if ((esp_reset_reason() == ESP_RST_TASK_WDT) || (esp_reset_reason() == ESP_RST_WDT)) {
    while (1) {
      digitalWrite(SDC_CTRL_PIN, LOW);
      digitalWrite(PWR_LED_PIN, HIGH);
    }
  }

  Serial2.begin(19200, SERIAL_8N1, 16, 17);
  Serial.begin(115200);
  twai_general_config_t noack_config = TWAI_GENERAL_CONFIG_DEFAULT((gpio_num_t)(CAN_TX), (gpio_num_t)(CAN_RX), TWAI_MODE_NO_ACK);
  ESP32Can.begin(ESP32Can.convertSpeed(500), CAN_TX, CAN_RX, 10, 10, nullptr, &noack_config);

  uint8_t j = 0;
  uint8_t i = 0;
  for (i = 0; i < NUM_SEG; i++) {
    for (j = 0; j < NUM_MOD_SEG; j++) {
      cellV[i][j] = xQueueCreate(1, sizeof(uint16_t));
      SOC1[i][j] = xQueueCreate(1, sizeof(uint8_t));
      SOC2[i][j] = xQueueCreate(1, sizeof(uint8_t));
      DCIR[i][j] = xQueueCreate(1, sizeof(uint16_t));
      SOC[i][j] = xQueueCreate(1, sizeof(uint8_t));
    }
    BAL[i] = xQueueCreate(1, sizeof(uint16_t));
  }
  TSCurrent = xQueueCreate(1, sizeof(float));
  SOCCoulombCountingTime = xQueueCreate(1, sizeof(unsigned long));
  ADS1115Current = xQueueCreate(1, sizeof(int16_t));
  VAT4300Current = xQueueCreate(1, sizeof(float));
  TSVoltage = xQueueCreate(1, sizeof(float));
  TSPower = xQueueCreate(1, sizeof(float));
  VAT4300OnTimeSeconds = xQueueCreate(1, sizeof(int32_t));

  uint8_t soc_def = 0;
  uint16_t dcir_def = 3500;
  uint16_t cellV_def = 0;
  uint16_t bal_def = 0;
  float ts_current_def = 0.0;
  unsigned long time_def = 0;
  int16_t ads1115_current_def = 0;
  int32_t vat4300_time_def = 0;

  for (i = 0; i < NUM_SEG; i++) {
    for (j = 0; j < NUM_MOD_SEG; j++) {
      xQueueOverwrite(SOC1[i][j], &soc_def);
      xQueueOverwrite(SOC2[i][j], &soc_def);
      xQueueOverwrite(DCIR[i][j], &dcir_def);
      xQueueOverwrite(SOC[i][j], &soc_def);
      xQueueOverwrite(cellV[i][j], &cellV_def);
    }
    xQueueOverwrite(BAL[i], &bal_def);
  }
  xQueueOverwrite(TSCurrent, &ts_current_def);
  xQueueOverwrite(SOCCoulombCountingTime, &time_def);
  xQueueOverwrite(ADS1115Current, &ads1115_current_def);
  xQueueOverwrite(VAT4300Current, &ts_current_def);
  xQueueOverwrite(TSVoltage, &ts_current_def);
  xQueueOverwrite(TSPower, &ts_current_def);
  xQueueOverwrite(VAT4300OnTimeSeconds, &vat4300_time_def);

  linduino_serial_mutex = xSemaphoreCreateMutex();
  i2c_mutex = xSemaphoreCreateMutex();
  rf24_mutex = xSemaphoreCreateMutex();
  telnet_mutex = xSemaphoreCreateMutex();
  twai_mutex = xSemaphoreCreateMutex();

  I2CADS1115.begin(21, 22, 100000);
  pinMode(ADS1115_RDY_PIN, INPUT_PULLUP);
  pinMode(RF24_IRQ_PIN, INPUT_PULLUP);
  attachInterrupt(ADS1115_RDY_PIN, ads1115ISR, FALLING);
  attachInterrupt(RF24_IRQ_PIN, rf24ISR, FALLING);
  digitalWrite(SDC_CTRL_PIN, LOW);
  digitalWrite(PWR_LED_PIN, HIGH);

  xTaskCreatePinnedToCore(TaskLinduinoCVComms, "Linduino CV Comms", 4096, NULL, 1, &Linduino_CV_Comms_Task_Handle, 1);
  xTaskCreatePinnedToCore(TaskUpdateSOC, "SOC Update", 2048, NULL, 1, &Update_SOC_Task_Handle, 1);
  xTaskCreatePinnedToCore(TaskUpdateDCIR, "DCIR Update", 2048, NULL, 1, &Update_DCIR_Task_Handle, 1);
  xTaskCreatePinnedToCore(TaskADS1115, "ADS1115 Comms", 4096, NULL, 1, &ADS1115_Task_Handle, 0);
  xTaskCreatePinnedToCore(TaskVAT4300, "VAT4300 RF24 Comms", 8192, NULL, 1, &VAT4300_Task_Handle, 0);
  xTaskCreatePinnedToCore(TaskBalancing, "Module Balancing", 2048, NULL, 1, &Balancing_Task_Handle, 1);
  xTaskCreatePinnedToCore(TaskUpdateTSCurrent, "TS Current Update w ADS115 and VAT4300", 2048, NULL, 1, &Update_TS_Current_Task_Handle, 1);
  xTaskCreatePinnedToCore(TaskSDCFault, "SDC Fault monitor", 2048, NULL, 1, &SDC_Fault_Task_Handle, 1);
  xTaskCreatePinnedToCore(TaskTelnetStreamPrintDebug, "Print Debug", 4096, NULL, 1, &TelnetStream_Print_Debug_Task_Handle, 1);
  xTaskCreatePinnedToCore(TaskOTAHandleAlive, "OTA handle", 16384, NULL, 1, &OTA_Handle_Alive_Task_Handle, 1);
  xTaskCreatePinnedToCore(TaskCANComms, "CAN comms", 8192, NULL, 1, &CAN_Comms_Task_Handle, 1);
}

void TaskLinduinoCVComms(void *pvParameters) {
  uint8_t initCodes[NUM_SEG] = { 0x01, 0x02, 0x03, 0x04, 0x05, 0x06 };
  uint8_t cellCodesL = NUM_MOD_SEG + 1;
  uint16_t cellCodes[cellCodesL];
  uint8_t x = 0x00;
  uint8_t crc = 0x00;
  uint16_t gen = 0x8380;
  uint8_t i = 0;
  uint8_t j = 0;
  uint8_t temp_byte = 0;
  uint8_t first_complete = 0;
  uint16_t balance_config = 0;
  for (j = 0; j < NUM_MOD_SEG; j++) {
    cellCodes[j] = 0x0000;
  }
  while (1) {
    if (xSemaphoreTake(linduino_serial_mutex, portMAX_DELAY) == pdTRUE) {
      xQueuePeek(BAL[i], &balance_config, portMAX_DELAY);
      for (j = 0; j < 4; j++) {
        temp_byte = temp_byte | (initCodes[i] << 5);
        temp_byte = temp_byte | (j << 3);
        temp_byte = temp_byte | (uint8_t)((balance_config >> (j * 3)) & 0x0007);
        Serial2.write(temp_byte);
        temp_byte = 0;
        vTaskDelay(1 / portTICK_PERIOD_MS);
      }
      xSemaphoreGive(linduino_serial_mutex);
    }
    vTaskDelay(50 / portTICK_PERIOD_MS);
    if (Serial2.available()) {
      x = Serial2.read();
      if (x != initCodes[i]) {
        while (Serial2.available()) {
          x = Serial2.read();
        }
        continue;
      } else {
        for (j = 0; j < NUM_MOD_SEG; j++) {
          x = Serial2.read();
          cellCodes[j] = (uint16_t)(x) << 8;
          x = Serial2.read();
          cellCodes[j] = cellCodes[j] | ((uint16_t)(x));
        }
        crc = Serial2.read();
        cellCodes[NUM_MOD_SEG] = 0x0000;
        uint8_t rsc = 0;
        uint8_t a = 0;
        int8_t b = 9;
        uint16_t tmp = 0x0000;
        uint16_t gen = 0x8380;
        uint16_t calc_crc = 0x0000;
        if (((cellCodes[0] & 0x8000) >> 15) == 0x0001) {
          calc_crc = (cellCodes[0] ^ gen);
        } else {
          calc_crc = cellCodes[0];
        }
        calc_crc = calc_crc & 0xFF80;
        while (rsc < 191) {
          tmp = uint16_t((calc_crc << 1) | ((cellCodes[a] << b) & 0x8000) >> 8);
          if (((tmp & 0x8000) >> 15) == 0x0001) {
            calc_crc = tmp ^ gen;
          } else {
            calc_crc = tmp;
          }
          calc_crc = calc_crc & 0xFF80;
          rsc++;
          if (b == 15) {
            b = -1;
            a++;
          }
          b++;
        }
        calc_crc = calc_crc >> 7;
        if (uint8_t(calc_crc) == crc) {
          for (j = 0; j < NUM_MOD_SEG; j++) {
            xQueueOverwrite(cellV[i][j], &cellCodes[j]);
          }
          i++;
          if (i >= NUM_SEG) {
            i = 0;
            if (first_complete == 0) {
              xTaskNotifyGive(Update_SOC_Task_Handle);
              first_complete = 1;
            }
          }
        }
      }
    }
  }
}

void TaskUpdateSOC(void *pvParameters) {
  ulTaskNotifyTake(pdTRUE, portMAX_DELAY);
  float disI = 0.0;
  uint8_t i = 0;
  uint8_t j = 0;
  uint8_t a = 0;
  uint16_t dcir_temp = 0;
  float ocv_temp = 0;
  float soc1_temp = 0.0;
  float soc2_temp = 0.0;
  uint8_t soc1 = 0;
  uint8_t soc2 = 0;
  uint8_t soc2_old = 0;
  uint16_t cellV_temp;
  uint8_t first = 1;
  float alpha = 0.0;
  float soc_final_temp = 0.0;
  uint8_t soc_final = 0;
  uint8_t soc1_valid = 0;
  uint8_t soc2_valid = 0;
  unsigned long old_time = 0;
  unsigned long new_time = 0;
  uint16_t bal_config = 0;
  uint8_t bal_flag = 0;
  uint8_t soc_minl = SOC_MIN_LIMIT;
  uint8_t soc_maxl = SOC_MAX_LIMIT;
  while (1) {
    xQueuePeek(TSCurrent, &disI, portMAX_DELAY);
    alpha = max(0.0F, (1 - (abs(disI) / I_SOC_TRESHOLD)));
    for (i = 0; i < NUM_SEG; i++) {
      xQueuePeek(BAL[i], &bal_config, portMAX_DELAY);
      for (j = 0; j < NUM_MOD_SEG; j++) {
        xQueuePeek(DCIR[i][j], &dcir_temp, portMAX_DELAY);
        xQueuePeek(cellV[i][j], &cellV_temp, portMAX_DELAY);
        bal_flag = (uint8_t)((bal_config >> j) & 0x0001);
        ocv_temp = (cellV_temp / 10000.0) + (dcir_temp / 1000000.0) * (disI + bal_flag * (cellV_temp / (BALANCE_RES_VALUE * 10000.0)));
        if (ocv_temp > 4.05) {
          for (a = 0; a < 4; a++) {
            soc1_temp += ocv_to_soc_above_4_05[a] * pow(ocv_temp, a);
          }
        } else if (ocv_temp < 3.45) {
          for (a = 0; a < 4; a++) {
            soc1_temp += ocv_to_soc_below_3_45[a] * pow(ocv_temp, a);
          }
        } else {
          for (a = 0; a < 4; a++) {
            soc1_temp += ocv_to_soc_middle[a] * pow(ocv_temp, a);
          }
        }
        soc1 = uint8_t(soc1_temp);
        soc1 = constrain(soc1, (uint8_t)(SOC_MIN_LIMIT), (uint8_t)(SOC_MAX_LIMIT));
        soc1_temp = 0.0;
        if ((soc1 >= SOC_MIN_LIMIT) && (soc1 <= SOC_MAX_LIMIT)) {
          soc1_valid = 1;
          xQueueOverwrite(SOC1[i][j], &soc1);
          if (first == 1) {
            xQueueOverwrite(SOC2[i][j], &soc1);
            soc2 = soc1;
            soc2_valid = 1;
          }
        } 
        if (first != 1) {
          xQueuePeek(SOC2[i][j], &soc2_old, portMAX_DELAY);
          xQueuePeek(SOCCoulombCountingTime, &old_time, portMAX_DELAY);
          new_time = millis();
          soc2_temp = (((soc2_old / 100.0) * (MOD_CAPACITY) - (disI * ((new_time - old_time) / (1000 * 3600)))) / MOD_CAPACITY) * 100.0;
          xQueueOverwrite(SOCCoulombCountingTime, &new_time);
          soc2 = uint8_t(soc2_temp);
          soc2 = constrain(soc2, (uint8_t)(SOC_MIN_LIMIT), (uint8_t)(SOC_MAX_LIMIT));
          if ((soc2 >= SOC_MIN_LIMIT) && (soc2 <= SOC_MAX_LIMIT)) {
            soc2_valid = 1;
            xQueueOverwrite(SOC2[i][j], &soc2);
          }
        }
        soc_final_temp = alpha * soc1 + (1.0 - alpha) * soc2;
        soc_final = uint8_t(soc_final_temp);
        if ((soc1_valid == 1) && (soc2_valid == 1)) {
          xQueueOverwrite(SOC[i][j], &soc_final);
        }
        soc1_valid = 0;
        soc2_valid = 0;
      }
    }
    if (first == 1) {
      first = 0;
      xTaskNotifyGive(Update_DCIR_Task_Handle);
      xTaskNotifyGive(Balancing_Task_Handle);
    }
    vTaskDelay(100 / portTICK_PERIOD_MS);
  }
}

void TaskUpdateDCIR(void *pvParameters) {
  ulTaskNotifyTake(pdTRUE, portMAX_DELAY);
  float disI = 0.0;
  uint8_t soc = 0;
  uint8_t i = 0;
  uint8_t j = 0;
  uint8_t a = 0;
  float ocv_temp = 0.0;
  float dcir_temp = 0.0;
  uint16_t dcir_new = 0;
  uint16_t dcir_old = 0;
  uint16_t dcir_final = 0;
  uint16_t cellV_temp = 0;
  uint16_t bal_config = 0;
  uint8_t bal_flag = 0;

  while (1) {
    xQueuePeek(TSCurrent, &disI, portMAX_DELAY);
    if (disI > I_DCIR_TRESHOLD) {
      for (i = 0; i < NUM_SEG; i++) {
        xQueuePeek(BAL[i], &bal_config, portMAX_DELAY);
        for (j = 0; j < NUM_MOD_SEG; j++) {
          xQueuePeek(SOC[i][j], &soc, portMAX_DELAY);
          if (soc > 95) {
            for (a = 0; a < 4; a++) {
              ocv_temp += soc_to_ocv_above_95[a] * pow(soc, a);
            }
          } else if (soc < 20) {
            for (a = 0; a < 4; a++) {
              ocv_temp += soc_to_ocv_below_20[a] * pow(soc, a);
            }
          } else {
            for (a = 0; a < 4; a++) {
              ocv_temp += soc_to_ocv_middle[a] * pow(soc, a);
            }
          }
          xQueuePeek(cellV[i][j], &cellV_temp, portMAX_DELAY);
          bal_flag = (uint8_t)((bal_config >> j) & 0x0001);
          dcir_temp = ((ocv_temp - cellV_temp) / (disI + bal_flag * (cellV_temp / (10000.0 * BALANCE_RES_VALUE)))) * 100.0;
          ocv_temp = 0.0;
          if (dcir_temp > 0.0) {
            dcir_new = uint16_t(dcir_temp);
            xQueuePeek(DCIR[i][j], &dcir_old, portMAX_DELAY);
            if ((dcir_new > DCIR_MIN_LIMIT) && (dcir_new < DCIR_MAX_LIMIT) && (abs(dcir_new - dcir_old) < DCIR_JUMP_LIMIT)) {
              dcir_final = uint16_t((1.0 - BETA) * dcir_old + BETA * dcir_new);
              xQueueOverwrite(DCIR[i][j], &dcir_final);
            }
          }
        }
      }
    }
    vTaskDelay(500 / portTICK_PERIOD_MS);
  }
}

void TaskADS1115(void *pvParameters) {
  uint8_t i = 0;
  uint8_t f = 1;
  uint8_t r = 0;
  uint8_t curReads = 0;
  int16_t cur = 0;
  int16_t first_sum = 0;
  uint8_t loop_count = 0;

  while (1) {
    switch (i) {
      case 0:
        if (xSemaphoreTake(i2c_mutex, portMAX_DELAY) == pdTRUE) {
          I2CADS1115.beginTransmission(0x48);
          I2CADS1115.write(0x01);
          I2CADS1115.write(0x03);
          I2CADS1115.write(0x80);
          f = I2CADS1115.endTransmission();
          xSemaphoreGive(i2c_mutex);
        }
        if (f == 0) {
          i = 1;
          f = 1;
        }
        break;
      case 1:
        if (xSemaphoreTake(i2c_mutex, portMAX_DELAY) == pdTRUE) {
          I2CADS1115.beginTransmission(0x48);
          I2CADS1115.write(0x02);
          I2CADS1115.write(0x00);
          I2CADS1115.write(0x00);
          f = I2CADS1115.endTransmission();
          xSemaphoreGive(i2c_mutex);
        }
        if (f == 0) {
          i = 2;
          f = 1;
        }
        break;
      case 2:
        if (xSemaphoreTake(i2c_mutex, portMAX_DELAY) == pdTRUE) {
          I2CADS1115.beginTransmission(0x48);
          I2CADS1115.write(0x03);
          I2CADS1115.write(0x80);
          I2CADS1115.write(0x00);
          f = I2CADS1115.endTransmission();
          xSemaphoreGive(i2c_mutex);
        }
        if (f == 0) {
          i = 3;
          f = 1;
        }
        break;
      case 3:
        if (xSemaphoreTake(i2c_mutex, portMAX_DELAY) == pdTRUE) {
          I2CADS1115.beginTransmission(0x48);
          I2CADS1115.write(0x01);
          I2CADS1115.write(0x83);
          I2CADS1115.write(0x80);
          f = I2CADS1115.endTransmission();
          xSemaphoreGive(i2c_mutex);
        }
        if (f == 0) {
          f = 1;
          ulTaskNotifyTake(pdTRUE, portMAX_DELAY);
          if (xSemaphoreTake(i2c_mutex, portMAX_DELAY) == pdTRUE) {
            I2CADS1115.beginTransmission(0x48);
            I2CADS1115.write(0x00);
            I2CADS1115.endTransmission();
            r = I2CADS1115.requestFrom(0x48, 2);
            xSemaphoreGive(i2c_mutex);
          }
          if (r == 2) {
            i = 4;
            r = 0;
          }
        }
        break;
      case 4:
        if (xSemaphoreTake(i2c_mutex, portMAX_DELAY) == pdTRUE) {
          if (I2CADS1115.available() >= 2) {
            cur = I2CADS1115.read();
            cur = (cur << 8) | (I2CADS1115.read());
          }
          xSemaphoreGive(i2c_mutex);
        }
        if (loop_count < 10) {
          first_sum += cur;
          loop_count++;
        } else if (loop_count == 10) {
          ADS1115_bias = first_sum / 10.0;
          loop_count++;
        } else {
          if (ADS1115Current != NULL) {
            xQueueOverwrite(ADS1115Current, &cur);
          }
        }
        if (curReads < ADS1115_CONFIG_REWRITE_CYCLES) {
          i = 3;
          curReads++;
        } else {
          i = 0;
          curReads = 0;
        }
        break;
      default:
        i = 0;
        break;
    }
    vTaskDelay(2 / portTICK_PERIOD_MS);
  }
}
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
void loop() {
}

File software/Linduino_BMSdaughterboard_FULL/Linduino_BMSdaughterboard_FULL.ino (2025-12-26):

#include <Arduino.h>
#include <stdint.h>
#include "Linduino.h"  //built in header files
#include "LT_SPI.h"
#include "LTC68041.h"
#include <SPI.h>

#define TOTAL_IC 6

uint16_t cell_codes[TOTAL_IC][12];
uint8_t tx_cfg[TOTAL_IC][6];
 uint32_t bal_reset = 0;
 
void init_cfg();

void setup() {
  // put your setup code here, to run once:
  Serial.begin(19200);
  LTC6804_initialize();
  init_cfg();
  wakeup_sleep();
  LTC6804_wrcfg(TOTAL_IC, tx_cfg);
  delay(10);
}

void loop() {
  // put your main code here, to run repeatedly:
  uint8_t c1 = 0x00;
  uint8_t c2 = 0x00;
  uint8_t c3 = 0x00;
  uint8_t c4 = 0x00;
  uint8_t seg1 = 0x00;
  uint8_t seg2 = 0x00;
  uint8_t seg3 = 0x00;
  uint8_t seg4 = 0x00;
  uint8_t j1 = 0x00;
  uint8_t j2 = 0x00;
  uint8_t j3 = 0x00;
  uint8_t j4 = 0x00;
  uint8_t i = 0;
  uint8_t j = 0;
  int error = -1;
  uint8_t rsc = 0;
  uint8_t a = 0;
  int8_t b = 9;
  uint16_t tmp = 0x0000;
  uint16_t gen = 0x8380;
  uint16_t calc_crc = 0x0000;
  uint16_t bal_cfg = 0x0000;
  uint8_t cellVsend[26];
  uint16_t cell_codes_temp[13];
 
  for (i = 0; i < 26; i++) {
    cellVsend[i] = 0;
  }
  if (Serial.available() >= 4) {
    c1 = Serial.read();
    c2 = Serial.read();
    c3 = Serial.read();
    c4 = Serial.read();
    seg1 = c1 >> 5;
    seg2 = c2 >> 5;
    seg3 = c3 >> 5;
    seg4 = c4 >> 5;
    if ((seg1 == seg2) && (seg2 == seg3) && (seg3 == seg4)) {
      wakeup_idle();
      LTC6804_adcv();
      delay(10);
      wakeup_idle();
      error = LTC6804_rdcv(0, TOTAL_IC, cell_codes);
      if (error != -1) {
        cellVsend[0] = seg1;
        for (i = 0; i < 12; i++) {
          cellVsend[2 * i + 1] = (uint8_t)((cell_codes[seg1 - 1][i] >> 8) & 0x00FF);
          cellVsend[2 * i + 2] = (uint8_t)(cell_codes[seg1 - 1][i] & 0x00FF);
        }
        rsc = 0;
        a = 0;
        b = 9;
        tmp = 0x0000;
        gen = 0x8380;
        calc_crc = 0x0000;
        for (i = 0; i < 12; i++) {
          cell_codes_temp[i] = cell_codes[seg1 - 1][i];
        }
        cell_codes_temp[12] = 0x0000;
        if (((cell_codes_temp[0] & 0x8000) >> 15) == 0x0001) {
          calc_crc = (cell_codes_temp[0] ^ gen);
        } else {
          calc_crc = cell_codes_temp[0];
        }
        calc_crc = calc_crc & 0xFF80;
        while (rsc < 191) {
          tmp = uint16_t((calc_crc << 1) | ((cell_codes_temp[a] << b) & 0x8000) >> 8);
          if (((tmp & 0x8000) >> 15) == 0x0001) {
            calc_crc = tmp ^ gen;
          } else {
            calc_crc = tmp;
          }
          calc_crc = calc_crc & 0xFF80;
          rsc++;
          if (b == 15) {
            b = -1;
            a++;
          }
          b++;
        }
        calc_crc = calc_crc >> 7;
        cellVsend[25] = (uint8_t)(calc_crc);
        for (i = 0; i < 26; i++) {
          Serial.write(cellVsend[i]);
          delay(1);
        }
      }
      tx_cfg[seg1 - 1][4] = 0x00;
      tx_cfg[seg1 - 1][5] = 0x00;
      j1 = (c1 >> 3) & 0x03;
      j2 = (c2 >> 3) & 0x03;
      j3 = (c3 >> 3) & 0x03;
      j4 = (c4 >> 3) & 0x03;
      bal_cfg = bal_cfg | (((uint16_t)(c1 & 0x07)) << (j1 * 3));
      bal_cfg = bal_cfg | (((uint16_t)(c2 & 0x07)) << (j2 * 3));
      bal_cfg = bal_cfg | (((uint16_t)(c3 & 0x07)) << (j3 * 3));
      bal_cfg = bal_cfg | (((uint16_t)(c4 & 0x07)) << (j4 * 3));
      tx_cfg[seg1 - 1][4] = (uint8_t)(bal_cfg & 0x00FF);
      tx_cfg[seg1 - 1][5] = (uint8_t)((bal_cfg >> 8) & 0x000F);
      wakeup_sleep();
      LTC6804_wrcfg(TOTAL_IC, tx_cfg);
      delay(10);
    }
  }
  if ((millis() - bal_reset) > 120000) {
    bal_reset = millis();
    init_cfg();
    wakeup_sleep();
    LTC6804_wrcfg(TOTAL_IC, tx_cfg);
    delay(10);
  }
}

void init_cfg() {
  for (short i = 0; i < TOTAL_IC; i++) {
    tx_cfg[i][0] = 0xFE;
    tx_cfg[i][1] = 0x00;
    tx_cfg[i][2] = 0x00;
    tx_cfg[i][3] = 0x00;
    tx_cfg[i][4] = 0x00;
    tx_cfg[i][5] = 0x00;
  }
}

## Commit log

2025-12-26 PCB files
    [BMS Daughterboard.kicad_pcb, BMS Daughterboard.kicad_sch, PC817.step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]
2025-12-27 new dir
    [BMS Daughterboard.kicad_pcb, BMS Daughterboard.kicad_sch, PC817.step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]
2025-12-27 added README with PCB pictures
2025-12-27 Added PCB pictures

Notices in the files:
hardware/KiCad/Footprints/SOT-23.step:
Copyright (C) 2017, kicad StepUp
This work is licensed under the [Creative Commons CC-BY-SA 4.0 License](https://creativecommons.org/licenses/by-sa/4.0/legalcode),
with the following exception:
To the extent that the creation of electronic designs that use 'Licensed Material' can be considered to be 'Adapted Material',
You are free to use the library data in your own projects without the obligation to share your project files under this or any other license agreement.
